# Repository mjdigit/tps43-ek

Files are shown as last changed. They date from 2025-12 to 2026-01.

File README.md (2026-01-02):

# tps43-ek
Experiment kit of Azoteq TPS43 for study in advance of designing [Girasole40](https://github.com/mjdigit/Girasole40).

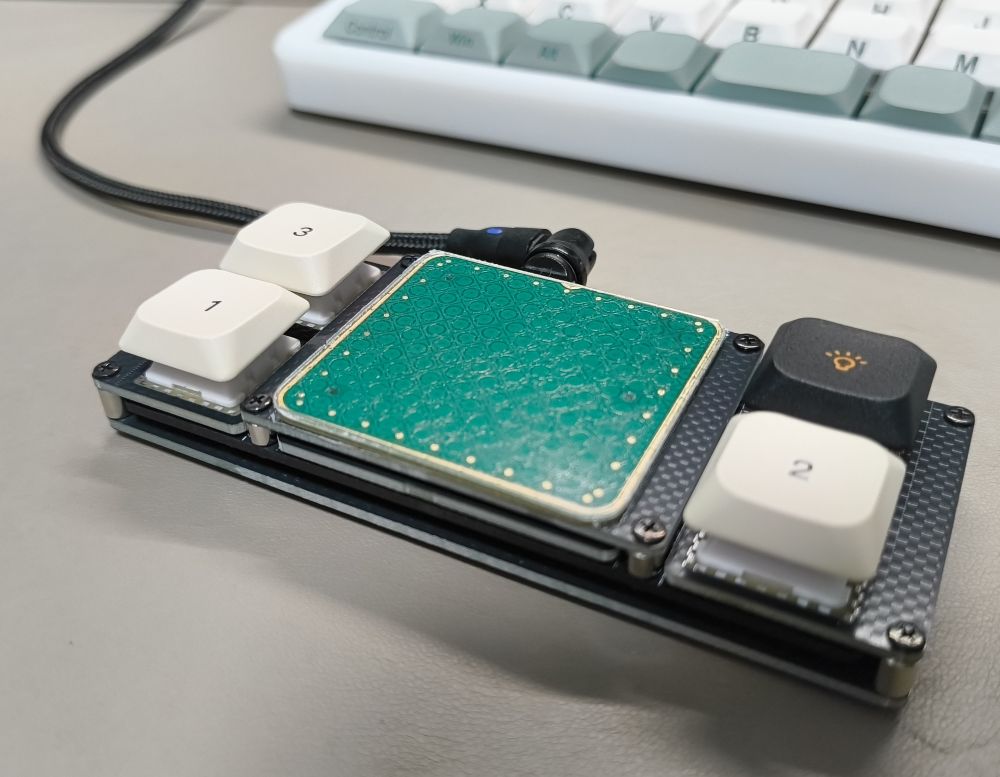
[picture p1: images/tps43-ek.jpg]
photo of tps43-ek


## Parts List (WIP)
(In study)

### Parts need to be prepared/purchased
|Part|Quantity|Where I bought it|Remarks|
|---|---|---|---|
|Wired controller board|1|AliExpress|RP2040-Zero (w/ pin headers)|
|Choc socket|4|yushakobo|e.g. Kailh PG1350 KeySwitches Contact (CPG135001S30)|
|Choc V2 switch|4|AliExpress|-|
|Keycap|4|AliExpress|-|
|Touchpad Module TPS43|1|MOUSER|-|
|Polycarbonate sheet for touchpad (0.5mm thickness) <br/>or<br/> PVC sheet for touchpad (0.5mm thikness)|1|Amazon|Need to be cut to suit TPS43|
|PET double-sided adhesive sheet|1|Amazon|Need to be cut to suit TPS43|
|M2 Spacer (3.5mm)|4|yushakobo|-|
|M2 Spacer (5.0mm)|4|yushakobo|-|
|M2 screw (3.5mm)|16|yushakobo|-|
|FPC cable (6pin, 0.5mm pitch, 50mm length)|1|Amazon|-|
|Diode|4|MOUSER|1N4148W|
|Resister 1608 1Kohm|2|akizukidenshi|-|
|Capaciter 1608 10uF|1|akizukidenshi|-|
|FPC socket (6pin, 0.5mm pitch)|1|Amazon|-|
|Rubber feet|5|Amazon|-|

### Parts need to be ordered/printed
|Part|Quantity|Remarks|
|---|---|---|
|Touchpad mount plate|1|<image src="images/TouchpadMountPlate.png" height="100px"/><br>gerber/gerber-touchpad.zip|
|Top plate|1|<image src="images/TopPlate.png" height="100px"/><br>gerber/gerber-top.zip|
|Main plate|1|<image src="images/MainPlate.png" height="100px"/><br>gerber/gerber.zip|
|Bottom plate|1|<image src="images/BottomPlate.png" height="100px"/><br>gerber/gerber-bottom.zip|

## Build Guide (WIP)
### !!! Important Notice !!!
Since I had placed SCL on pin0 and SDA on pin1, which assignment does not work on RP2040-Zero I2C0, some hand bridging is required.
There is no plan to be fix the gerber because this tps-43ek is just experimental project towards Girasole40.

### Assemble passive components on main plate
#### Front side
Solder FPC socket on the main plate.

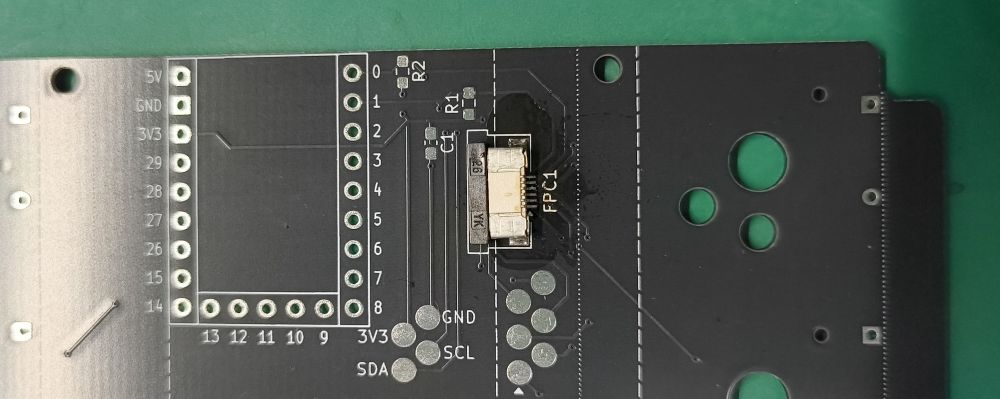
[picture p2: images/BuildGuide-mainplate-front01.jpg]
Build Guide-Mainplate Front 01


It's better to check resistance between the pads on main plate and TPS43 with connecting each other to check it successfully soldered.

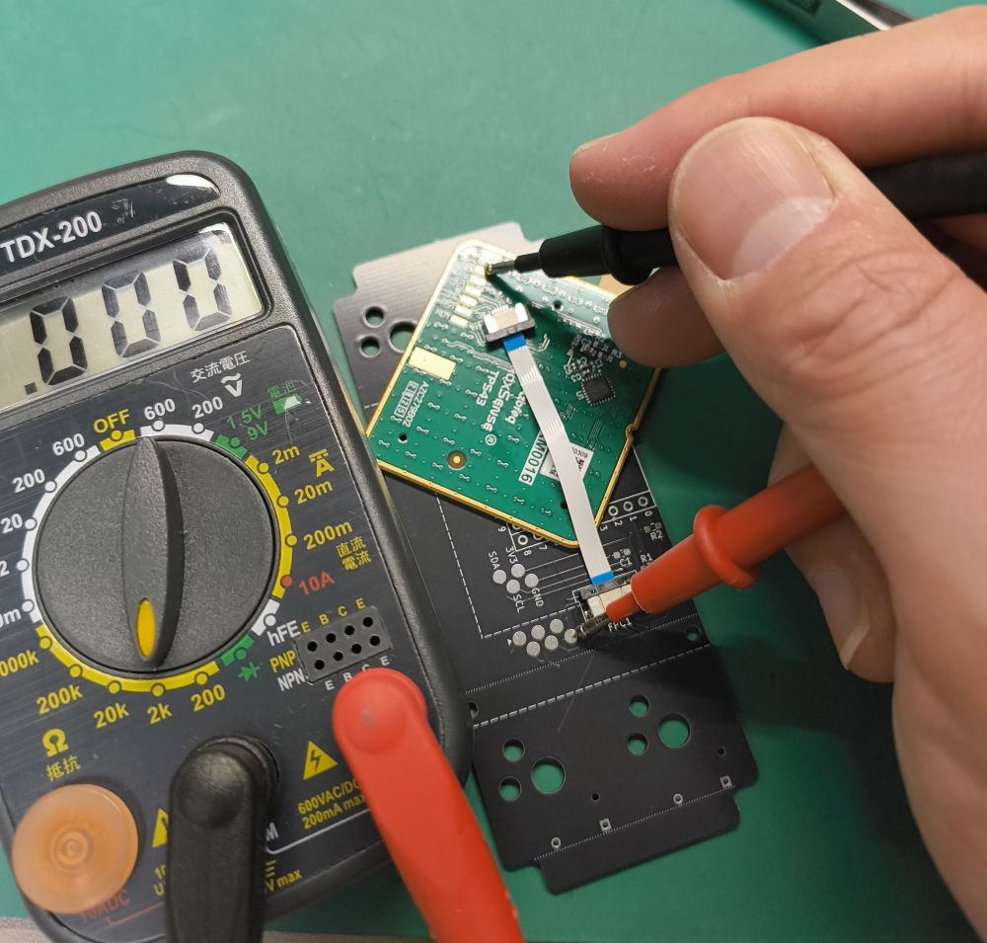
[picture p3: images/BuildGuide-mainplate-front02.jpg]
Build Guide-Mainplate Front 02


Solder resisters and a capacitor on front side of the main plate.

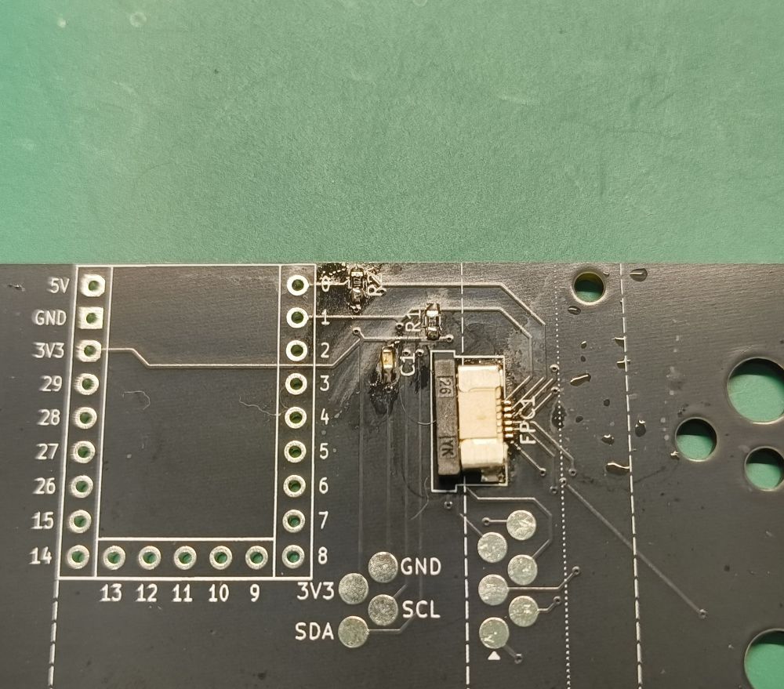
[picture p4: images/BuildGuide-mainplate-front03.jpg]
Build Guide-Mainplate Front 03


#### Back side
Solder diodes then switch sockets on back side of the main plate.

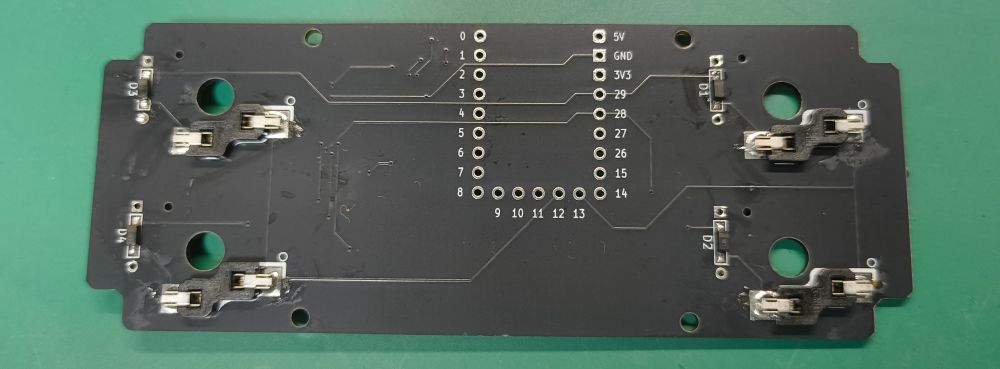
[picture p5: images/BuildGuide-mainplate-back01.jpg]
Build Guide-Mainplate Back 01


#### RP2040-Zero
Put pin headers then put RP2040-Zero on front side (DO NOT solder yet). 

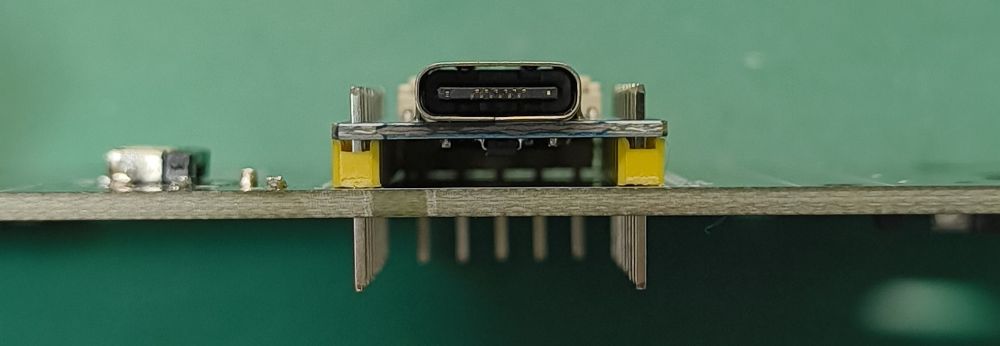
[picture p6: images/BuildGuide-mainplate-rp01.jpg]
Build Guide-Mainplate RP2040 01


Solder the pin headers on back side.

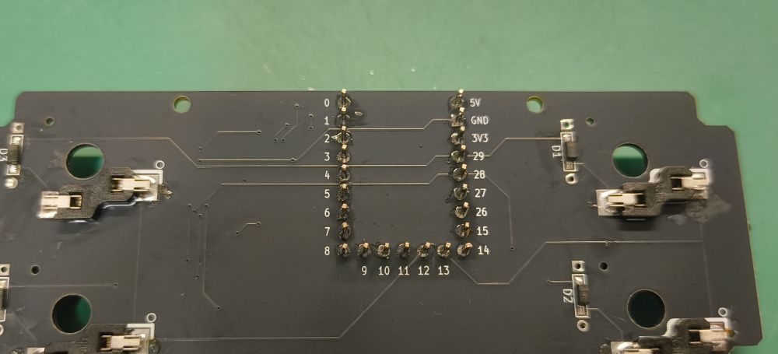
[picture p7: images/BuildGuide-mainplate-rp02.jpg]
Build Guide-Mainplate RP2040 02


Put off RP2040-Zero then remove yellow plastic parts.

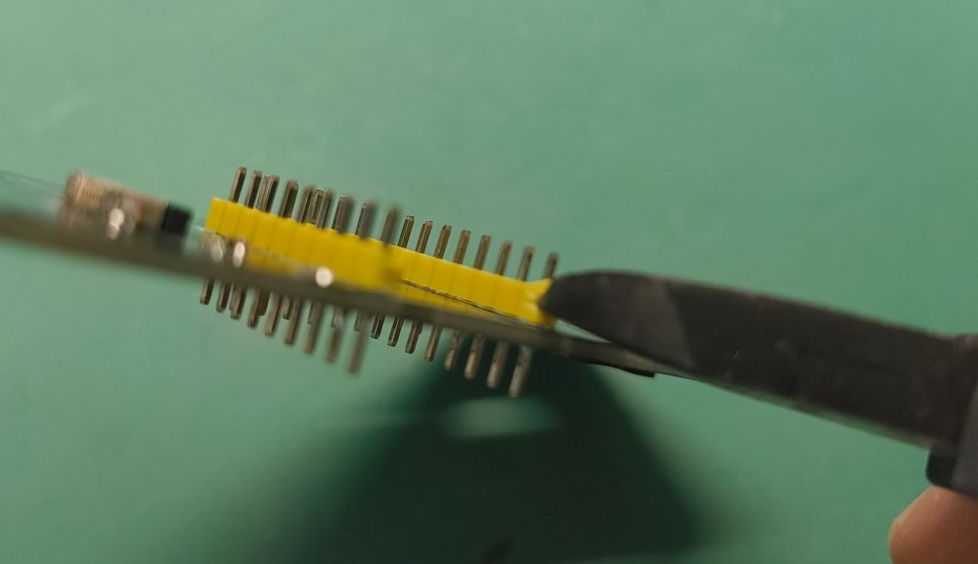
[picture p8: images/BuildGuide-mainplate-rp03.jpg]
Build Guide-Mainplate RP2040 03


Put RP2040-Zero again and solder it. Then cutoff the pins on Front side and Back side using nipper.

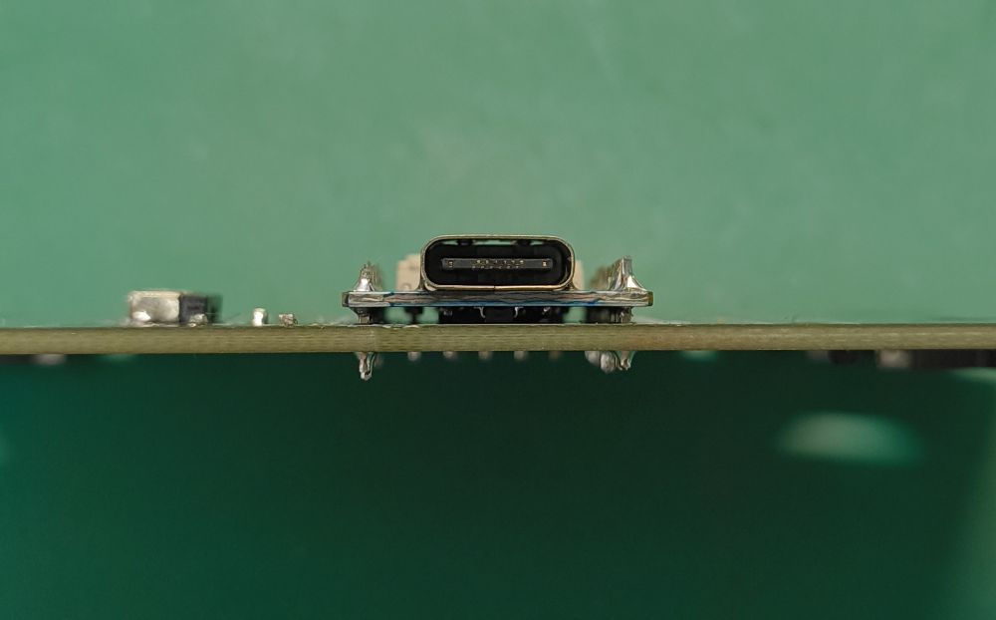
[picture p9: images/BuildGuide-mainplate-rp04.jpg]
Build Guide-Mainplate RP2040 04


#### Work Around: Replace SCL and SDA
As written on "Important Notice", it is required to place SDA on pin0 and SCL on pin1. Please connect each other in the below pads the cutoff the wire towards FPC connector.

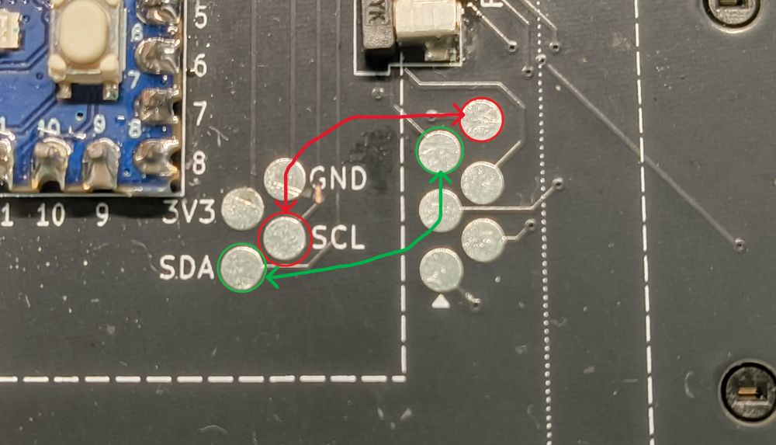
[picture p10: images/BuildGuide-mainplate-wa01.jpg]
Build Guide-Mainplate work around 01


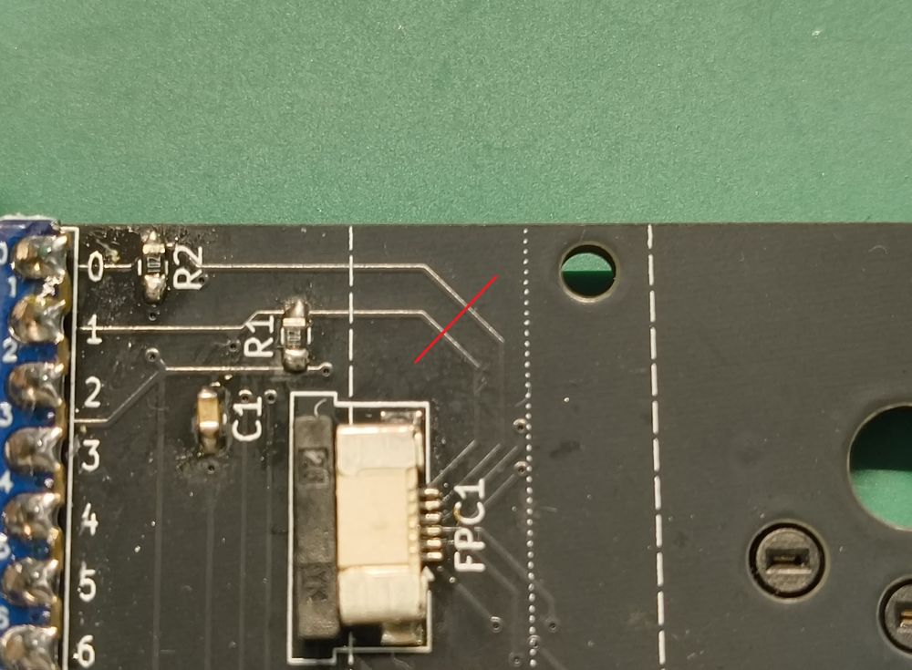
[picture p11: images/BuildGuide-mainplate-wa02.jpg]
Build Guide-Mainplate work around 02


#### Check whether touchpad works
Connect the main plate and TPS43 using FPC connector.

Connect your PC to RP2040-Zero with pushing BOOT switch. RP2040-Zero will be recognized as mass strage "RPI-RP2". Put the .uf2 file build by the following instruction into it.

Touch TPS43 and check whether touchpad works.

### Assemble the touchpad
Cut PET double-sided adhesive sheet to suit TPS43.

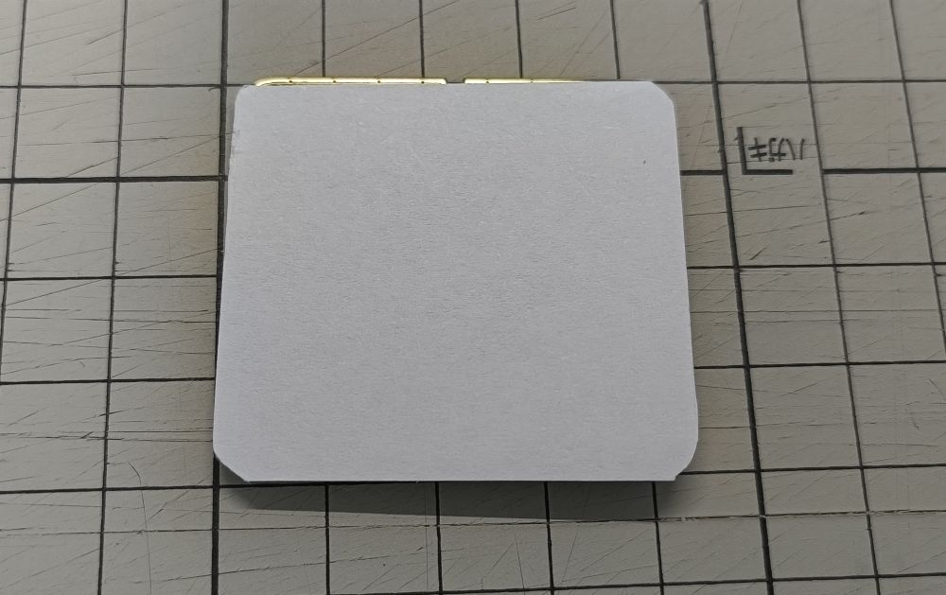
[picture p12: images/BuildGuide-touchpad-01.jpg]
Build Guide-Touchpad step 01


Adhere Polycarbonate sheet on TPS43 then cut it to suit TPS43.

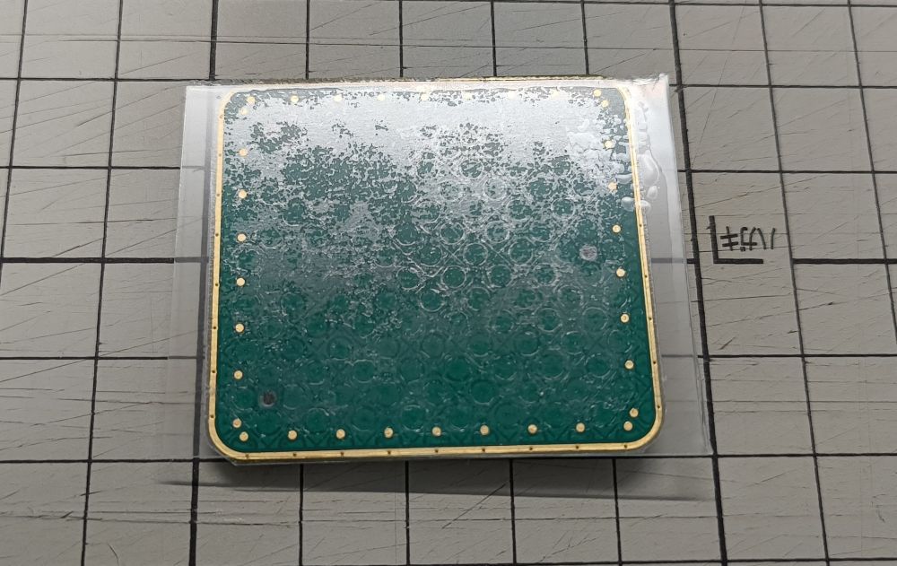
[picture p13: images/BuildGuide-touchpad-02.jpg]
Build Guide-Touchpad step 02


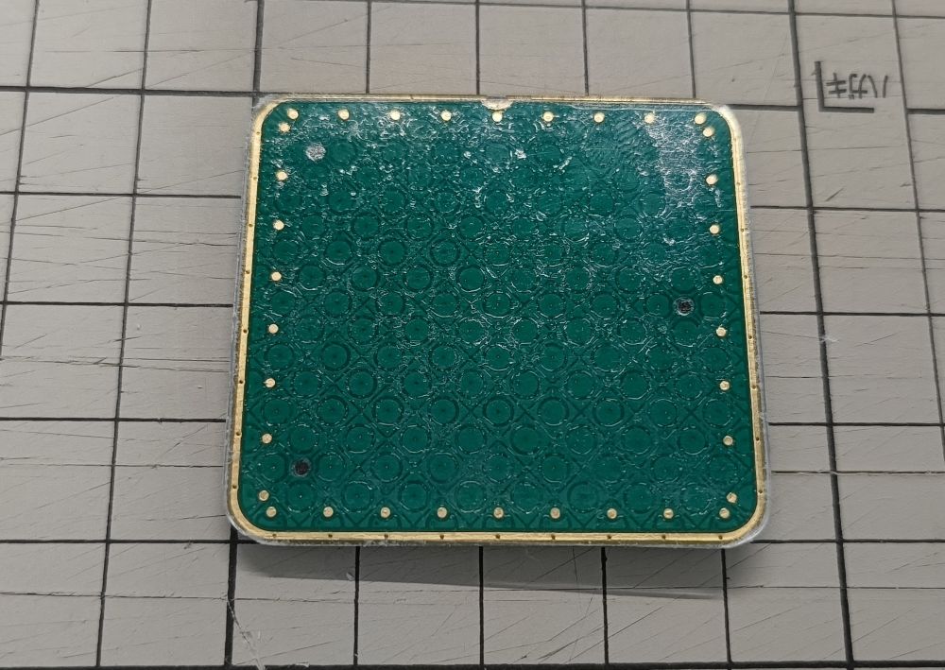
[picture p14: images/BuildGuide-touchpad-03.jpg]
Build Guide-Touchpad step 03


Put double-sided tape on inside on dashed line of the Touchpad mount plate.

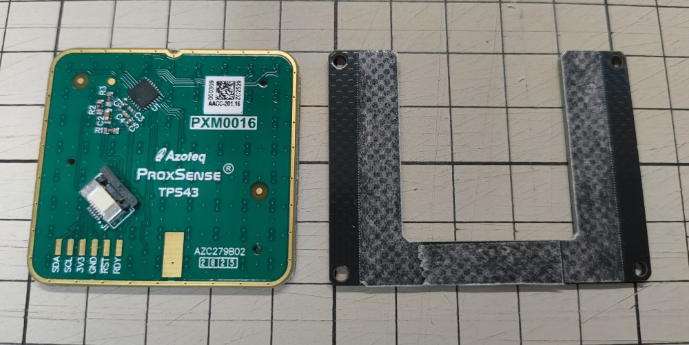
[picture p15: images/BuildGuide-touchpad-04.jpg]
Build Guide-Touchpad step 04


Then, put the plate onto TPS43.

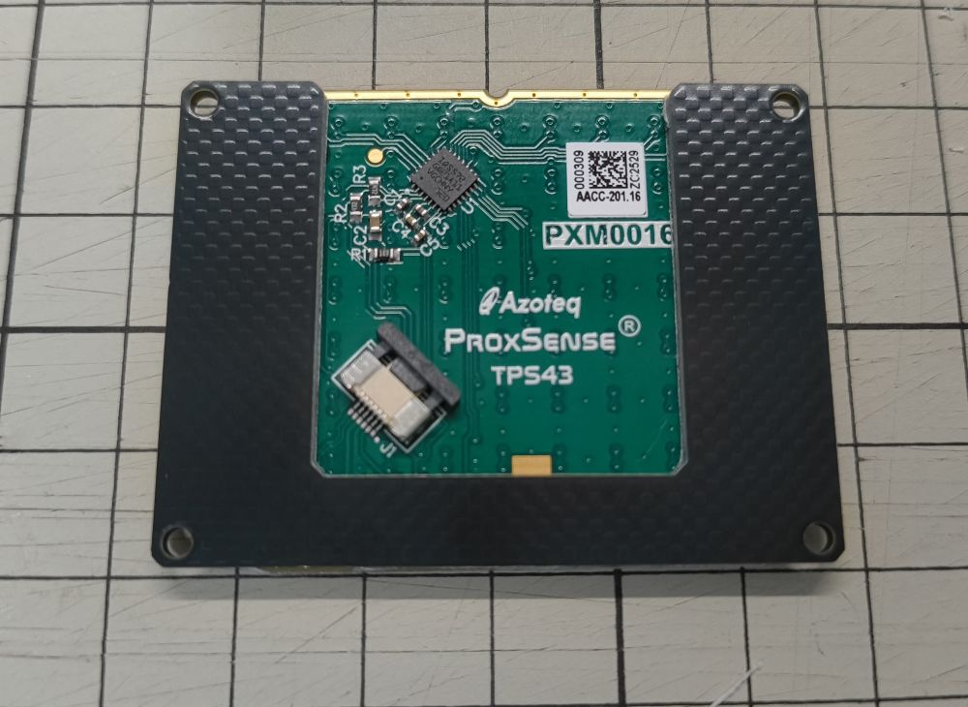
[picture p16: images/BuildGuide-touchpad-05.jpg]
Build Guide-Touchpad step 05


Note that you can also use PVC sheet instead of Polycarbonate sheet, though I feel touch experience is better on Polycarbonate sheet.

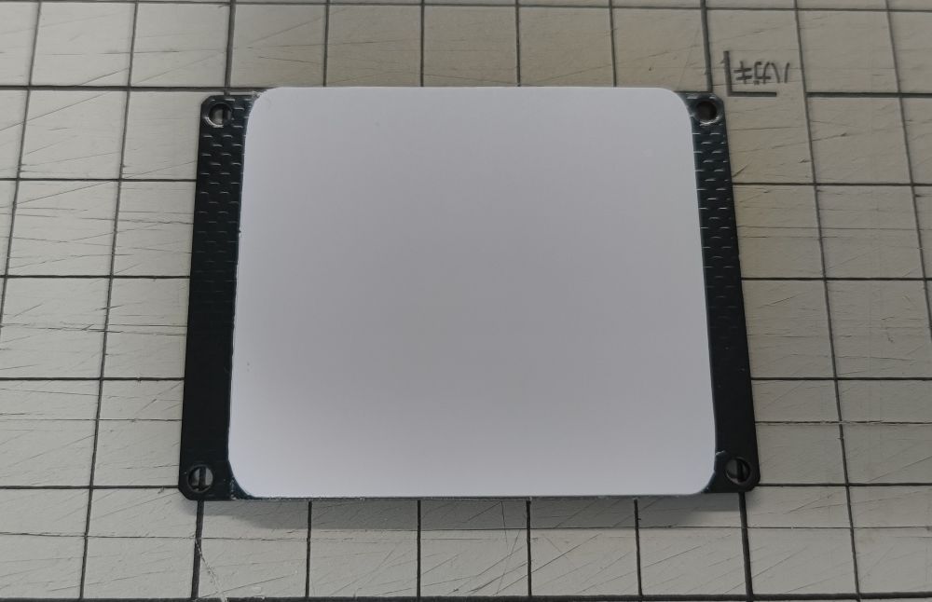
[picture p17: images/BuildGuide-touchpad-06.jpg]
Build Guide-Touchpad a case using PVC sheet


### Assemble plates
Put top plate on the main plate. Then put keyboard switches.

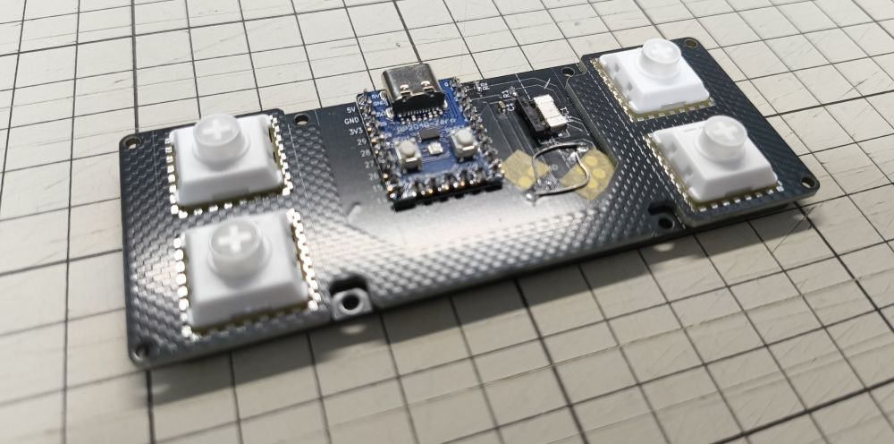
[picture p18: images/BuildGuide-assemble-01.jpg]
Build Guide-Assemble step 01


Connect the touchpad plate and the main plate with FPC cable.

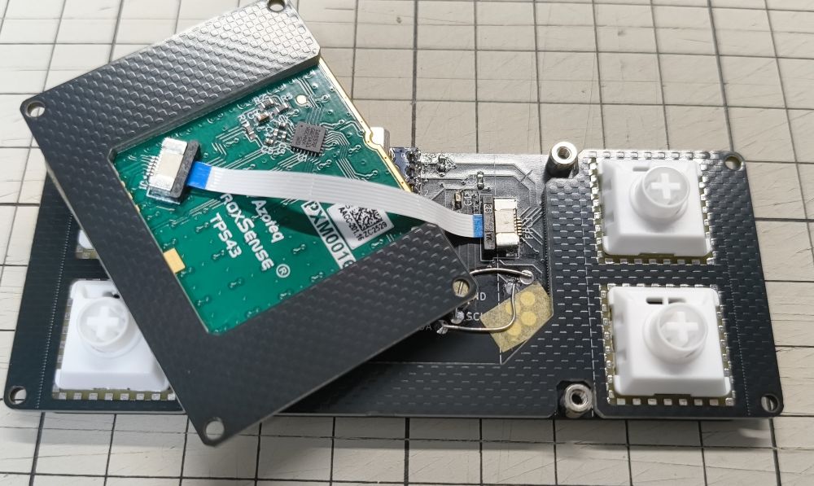
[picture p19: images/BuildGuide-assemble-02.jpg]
Build Guide-Assemble step 02


Then put the touchpad plate on the main plate using 3.5mm spacers and screws.

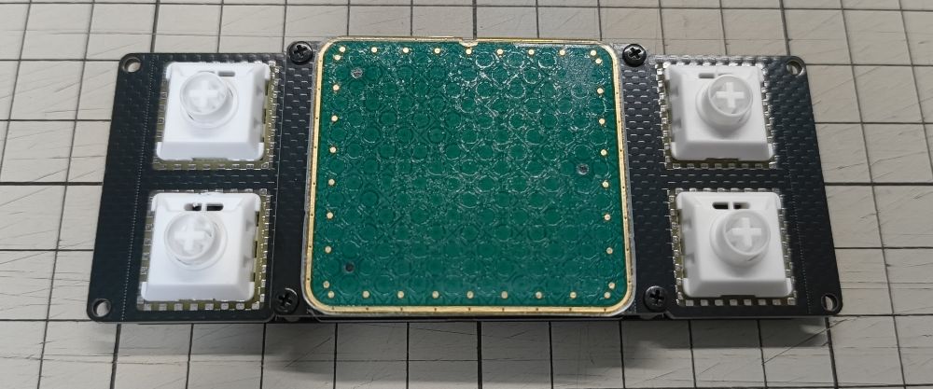
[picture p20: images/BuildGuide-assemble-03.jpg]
Build Guide-Assemble step 03


Put the plates on bottom plate using spacers and screws. And put keycaps.

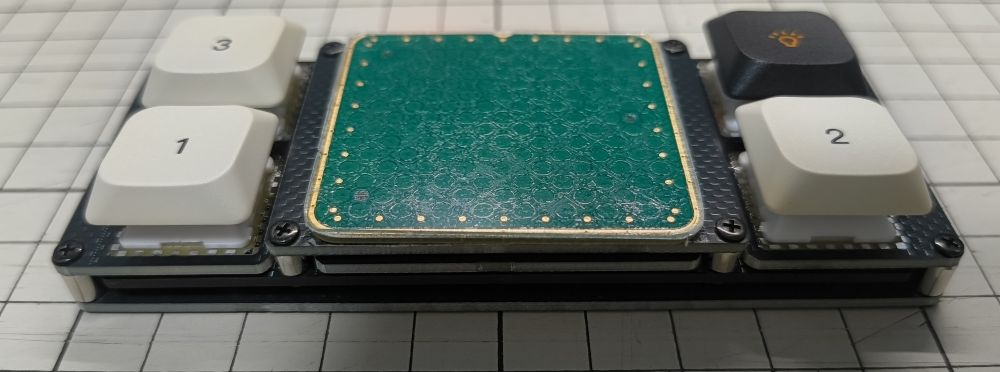
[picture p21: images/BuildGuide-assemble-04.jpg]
Build Guide-Assemble step 04


Finally, put rubber feets on the bottom plate.

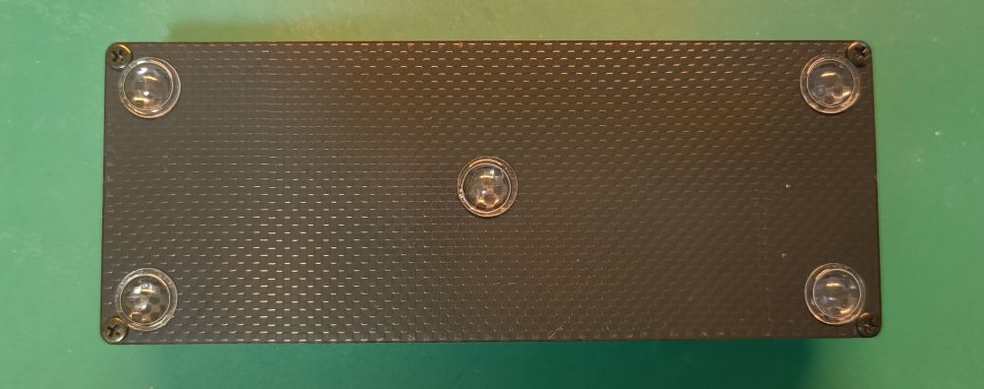
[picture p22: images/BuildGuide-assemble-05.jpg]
Build Guide-Assemble step 05


## Default layout
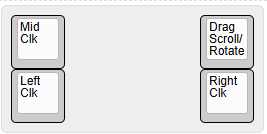
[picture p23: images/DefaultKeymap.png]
Default Keymap


You can rotate touchpad and keys using rotate layer.

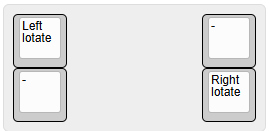
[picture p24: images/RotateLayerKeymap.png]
Rotate Layer Keymap


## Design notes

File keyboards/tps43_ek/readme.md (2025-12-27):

# tps43_ek

tps43_ek

*A short description of the keyboard/project*

* Keyboard Maintainer: [digit](https://github.com/mjdigit)
* Hardware Supported: *The PCBs, controllers supported*
* Hardware Availability: *Links to where you can find this hardware*

Make example for this keyboard (after setting up your build environment):

    make tps43_ek:default

Flashing example for this keyboard:

    make tps43_ek:default:flash

See the [build environment setup](https://docs.qmk.fm/#/getting_started_build_tools) and the [make instructions](https://docs.qmk.fm/#/getting_started_make_guide) for more information. Brand new to QMK? Start with our [Complete Newbs Guide](https://docs.qmk.fm/#/newbs).

## Bootloader

Enter the bootloader in 3 ways:

* **Bootmagic reset**: Hold down the key at (0,0) in the matrix (usually the top left key or Escape) and plug in the keyboard
* **Physical reset button**: Briefly press the button on the back of the PCB - some may have pads you must short instead
* **Keycode in layout**: Press the key mapped to `QK_BOOT` if it is available

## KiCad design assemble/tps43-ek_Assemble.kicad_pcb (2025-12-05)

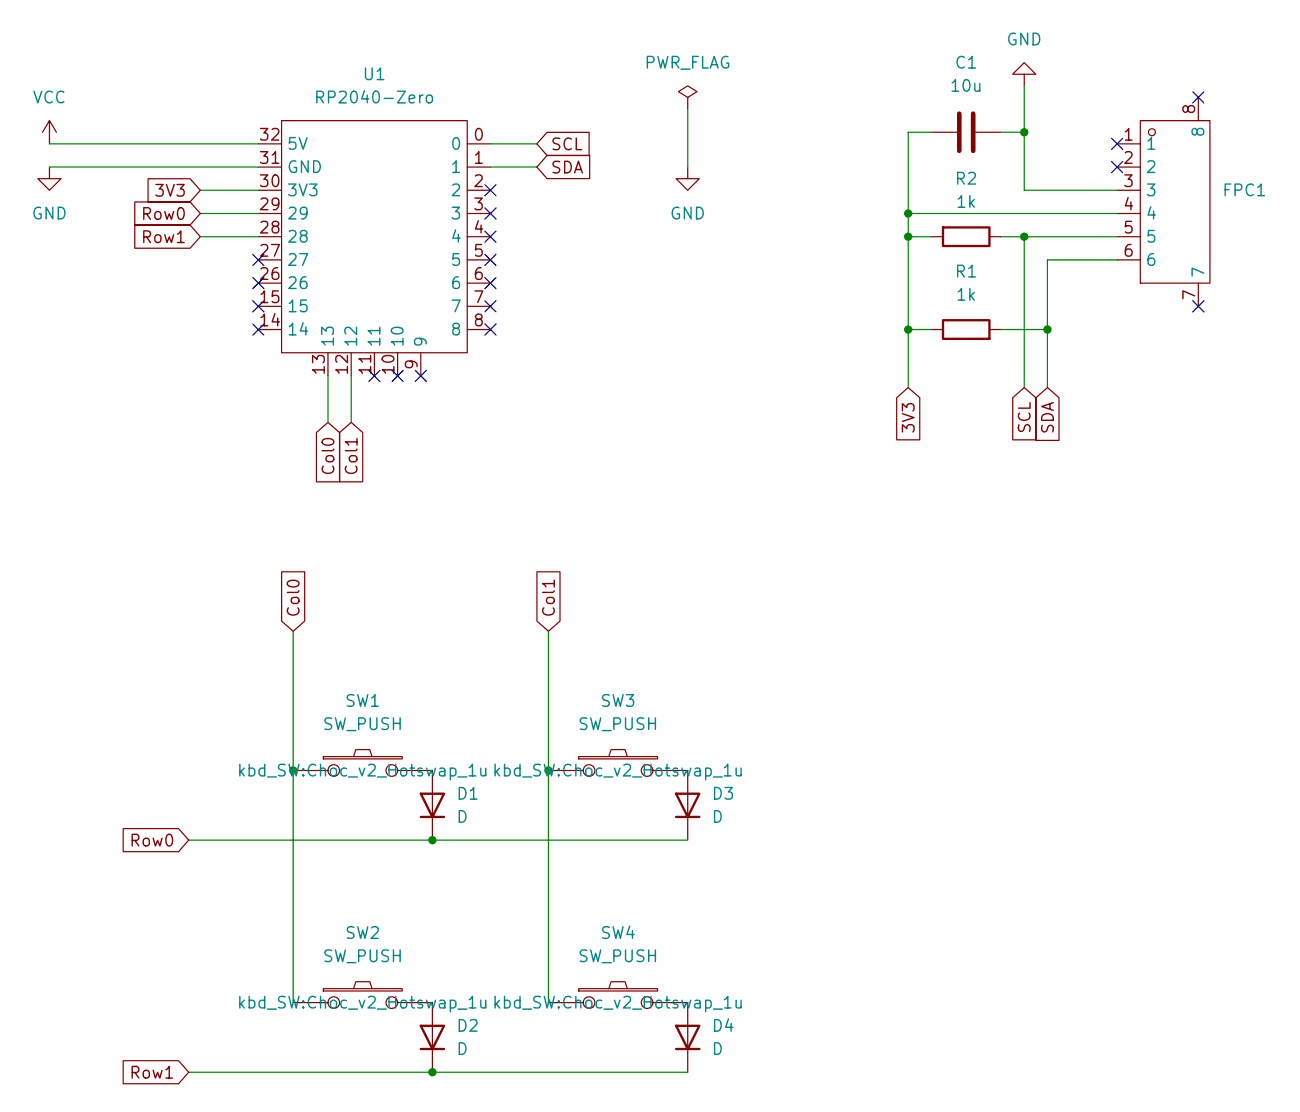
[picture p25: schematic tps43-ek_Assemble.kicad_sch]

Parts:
C1: 10u; C_0603_1608Metric_Pad1.08x0.95mm_HandSolder
D1, D2, D3, D4: D; Diode_TH_SMD
FPC1: FPC-6p-P0.5mm; Manufacturer Part FPC-05F-6PH20; LCSC Part Name 翻盖式 卧贴 P数:6P 间距:0.5mm
R1, R2: 1k; R_0603_1608Metric_Pad0.98x0.95mm_HandSolder
SW1, SW2, SW3, SW4: SW_PUSH; Choc_v2_Hotswap_1u
U1: RP2040-Zero

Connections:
3V3: C1.1, FPC1.4, R1.1, R2.2, U1.30 (3V3)
Col0: SW1.1, SW2.1, U1.13
Col1: SW3.1, SW4.1, U1.12
GND: C1.2, FPC1.3, U1.31 (GND)
unnamed: D1.2 (A), SW1.2
unnamed: D2.2 (A), SW2.2
unnamed: D3.2 (A), SW3.2
unnamed: D4.2 (A), SW4.2
Row0: D1.1 (K), D3.1 (K), U1.29
Row1: D2.1 (K), D4.1 (K), U1.28
SCL: FPC1.5, R2.1, U1.0
SDA: FPC1.6, R1.2, U1.1
VCC: U1.32 (5V)

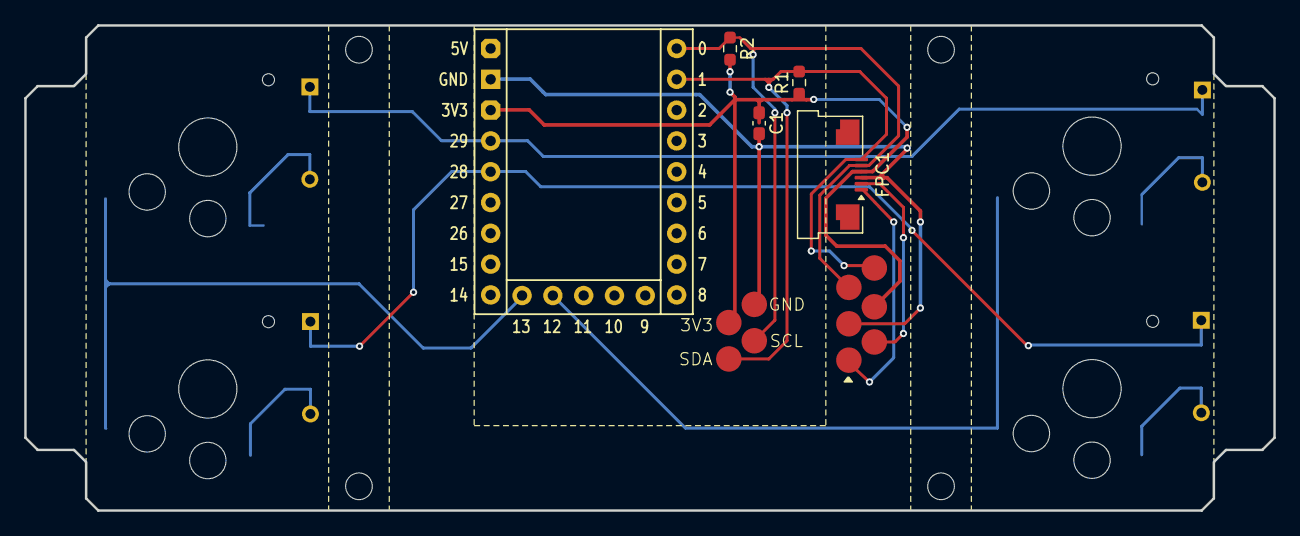
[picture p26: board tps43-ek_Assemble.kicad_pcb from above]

Board: 2 copper layers, 103.0 x 40.0 mm, 17 parts (0 on the bottom side), 12 nets.

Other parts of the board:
Ref**: M2_ScrewHole
Ref**#2, Ref**#3, Ref**#4: M2_ScrewHole

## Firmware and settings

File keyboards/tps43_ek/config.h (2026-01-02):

#pragma once

#define I2C_DRIVER I2CD0
#define I2C1_SDA_PIN GP0
#define I2C1_SCL_PIN GP1

#define AZOTEQ_IQS5XX_TPS43 1
#define AZOTEQ_IQS5XX_PRESS_AND_HOLD_ENABLE true
#define AZOTEQ_IQS5XX_HOLD_TIME 100
#define AZOTEQ_IQS5XX_SCROLL_INITIAL_DISTANCE 10

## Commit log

2025-12-05 Add KiCad assemble files and garber files of a trial design.
    [tps43-ek_Assemble.kicad_pcb, tps43-ek_Assemble.kicad_sch]
2025-12-13 Added assemble files and preliminaly build guide. (#2)
2025-12-27 Making QMK firmware. Touchpad is not working yet.
    [config.h]
2025-12-27 Making QMK firmware. Touchpad works with swapping SCL & SCA, but, need some more adjustment.
    [config.h]
2026-01-01 Renewed assemble instruction on README.md (#3)
